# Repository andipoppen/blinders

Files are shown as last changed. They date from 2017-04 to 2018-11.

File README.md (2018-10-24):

# BLE controlled and motorized window blind

This project is a based on a [motorized window blind](https://www.instructables.com/id/Motorized-WiFi-IKEA-Roller-Blind/) that is using the IKEA Tupplur blind. 

The difference from the original is that this project uses BLE to control the window blind and the BLE module is built in the motor holder.

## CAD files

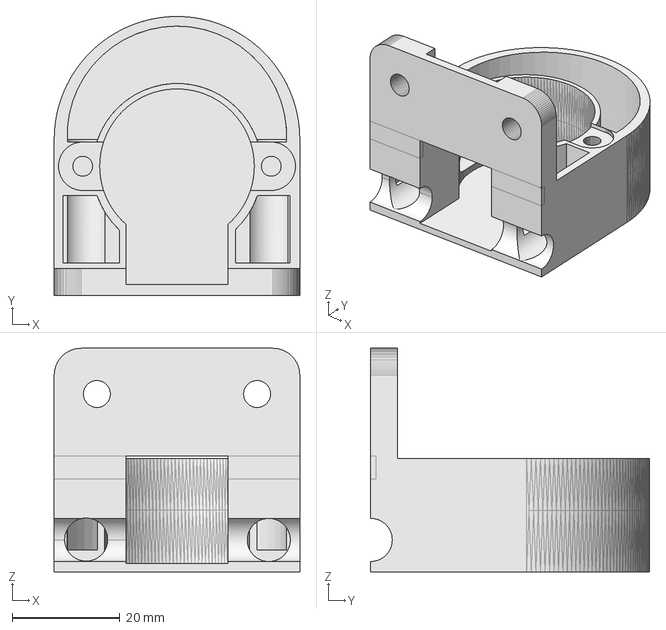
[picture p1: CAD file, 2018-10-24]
3d/mount_base.FCStd
45.6 x 51.8 x 41.5 mm

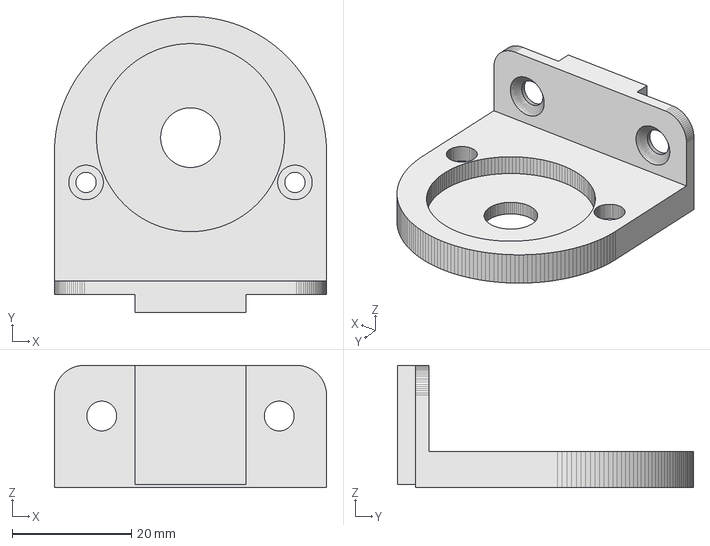
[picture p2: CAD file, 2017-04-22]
3d/mount_cover.FCStd
45.6 x 49.6 x 20.5 mm

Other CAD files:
3d/mount_base.stl
3d/mount_cover.stl

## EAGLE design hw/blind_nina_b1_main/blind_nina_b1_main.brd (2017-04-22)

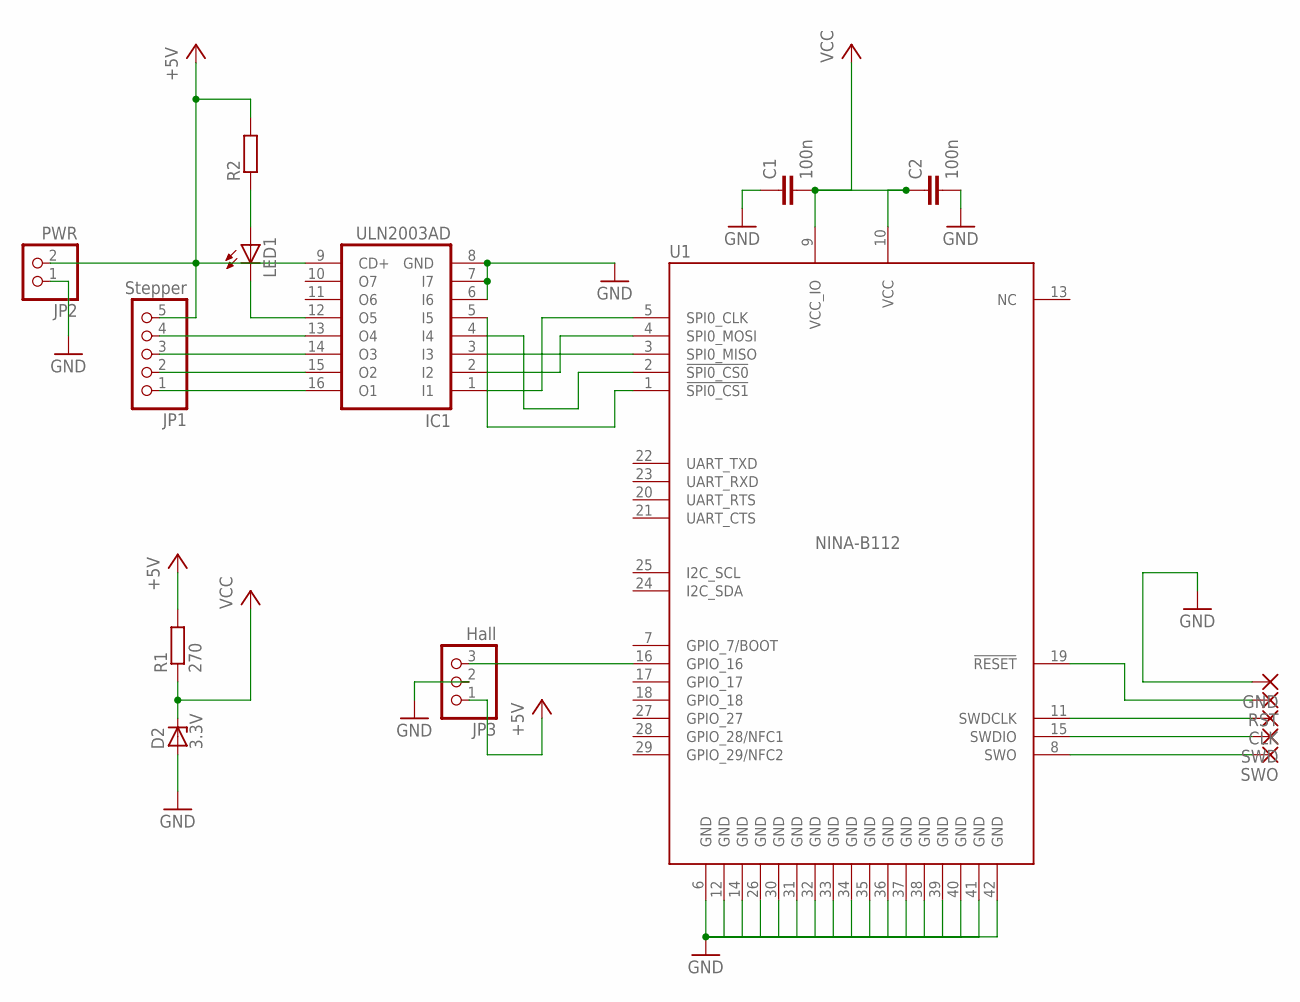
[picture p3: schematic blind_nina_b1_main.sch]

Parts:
C1, C2: 100n; C0603
CLK: SMD2; SMD1,27-2,54
D2: 3.3V; SOD80C
GND: SMD2; SMD1,27-2,54
IC1: ULN2003AD; SO16
JP1: Stepper; 1X05
JP2: PWR; 1X02
JP3: Hall; 1X03
LED1: LED_E; LED_1206
R1: 270; R1210W
R2: R-EU_R0603; R0603
RST: SMD2; SMD1,27-2,54
SWD: SMD2; SMD1,27-2,54
SWO: SMD2; SMD1,27-2,54
U1: NINA-B112; NINA112-42

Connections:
+5V: IC1.9 (CD+), JP1.5, JP2.2, JP3.1, R1.2, R2.2
GND: C1.1, C2.2, D2.A, GND.1, IC1.6 (I6), IC1.7 (I7), IC1.8 (GND), JP2.1, JP3.2, U1.6 (GND), U1.12 (GND), U1.14 (GND), U1.26 (GND), U1.30 (GND), U1.31 (GND), U1.32 (GND), U1.33 (GND), U1.34 (GND), U1.35 (GND), U1.36 (GND), U1.37 (GND), U1.38 (GND), U1.39 (GND), U1.40 (GND), U1.41 (GND), U1.42 (GND)
unnamed: IC1.1 (I1), U1.5 (SPI0_CLK)
unnamed: IC1.2 (I2), U1.4 (SPI0_MOSI)
unnamed: IC1.3 (I3), U1.3 (SPI0_MISO)
unnamed: IC1.4 (I4), U1.2 (!SPI0_CS0)
unnamed: SWO.1, U1.8 (SWO)
unnamed: IC1.16 (O1), JP1.1
unnamed: IC1.15 (O2), JP1.2
unnamed: IC1.14 (O3), JP1.3
unnamed: IC1.13 (O4), JP1.4
unnamed: SWD.1, U1.15 (SWDIO)
unnamed: CLK.1, U1.11 (SWDCLK)
unnamed: RST.1, U1.19 (!RESET)
unnamed: IC1.12 (O5), LED1.C
unnamed: JP3.3, U1.16 (GPIO_16)
unnamed: LED1.A, R2.1
unnamed: IC1.5 (I5), U1.1 (!SPI0_CS1!)
VCC: C1.2, C2.1, D2.C, R1.1, U1.9 (VCC_IO), U1.10 (VCC)

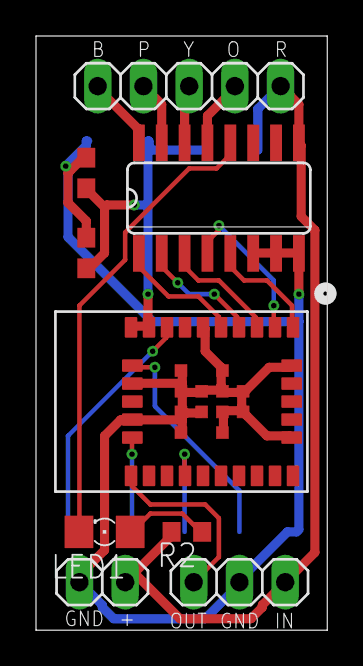
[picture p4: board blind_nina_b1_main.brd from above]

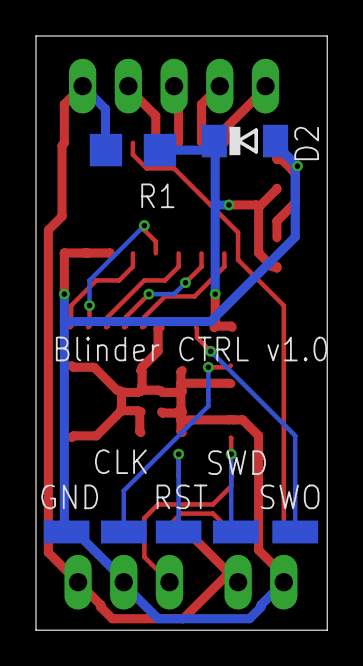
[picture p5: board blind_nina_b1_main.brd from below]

Board: 2 copper layers, 16.2 x 33.0 mm, 16 parts (7 on the bottom side), 19 nets.

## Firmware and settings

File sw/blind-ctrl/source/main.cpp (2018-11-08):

#include "mbed.h"
#include "sMotor.h"
#include "PinDetect.h"
#include <events/mbed_events.h>
#include <mbed.h>
#include "ble/BLE.h"
#include "BlindService.h"
//#include "DataStorage.h"

//DataStorage ds;
DigitalOut ledR(D9);
BLE* myBle = 0;

sMotor motor(D13, D11, D12, D10); // creates new stepper motor: IN1, IN2, IN3, IN4

int step_speed = 1000; // set default motor speed
int numstep = (4076/8)/10; // defines full turn of 360 degree

#define DEFAULT_DOWN_CALIBRATE_POSITION 12000
#define DEFAULT_DOWN_POSITION 8700 // 0x21FC bottom measured
#define DEFAULT_UP_POSITION 100


static int32_t _position = 0; // This is the position where the HALL effekt magnetic sensor is triggered
static int32_t _upPosition = DEFAULT_UP_POSITION; // Slighlty below the HALL effect sensor
static int32_t _bottomPosition = DEFAULT_DOWN_POSITION; // Bottom position of the blind
static int32_t _topPosition = -DEFAULT_DOWN_POSITION*2 - DEFAULT_UP_POSITION; // Top position of the blind. Can actually not go all the way but to make calibration possible from the bottom position

void handleHallSensorFall();

DigitalOut actuatedLED(LED1, 0);

InterruptIn hallSensorIn(A5); // NINA_B1_GPIO_16

const static char     DEVICE_NAME[] = "Blinds";
static const uint16_t uuid16_list[] = { BlindService::BLIND_SERVICE_UUID };

static EventQueue eventQueue(
    /* event count */10 * /* event size */ 32
    );

BlindService *blindServicePtr;


PinDetect pin(SW1);

enum State {
    WaitForTopPos,
    IdleTop,
    IdleBottom,
    Going2Top,
    Going2Bottom,
    Failure
};


static void enterGoing2Top();
static void enterFailure();
static void exitGoing2Top();
static void stepMotorUp();
static void stepMotorDown();


static State _state = IdleBottom;

#define SET_STATE(state) set_state(state,#state)

void set_state(State state, const char *state_str)
{
    _state = state;
    printf("State change to: %s\n", state_str);
}

void stepMotorUp()
{
    motor.step(numstep*100, 1, step_speed); // number of steps, direction, speed
    _position -= numstep;
    motor.disable();
}

void stepMotorDown()
{
    motor.step(numstep*100, 0, step_speed); // number of steps, direction, speed
    _position += numstep;
    motor.disable();
}

static void decrease_position()
{
    _position -= numstep;
    myBle->gattServer().write(blindServicePtr->getValueHandlePos(), (uint8_t*)&_position, 4);
    printf("Pos = %d\n", _position);
}

static void increase_position()
{
    _position += numstep;
    myBle->gattServer().write(blindServicePtr->getValueHandlePos(), (uint8_t*)&_position, 4);
    printf("Pos = %d\n", _position);
}

static void motor_thread() {
    int count = 0;
    ledR = 0;
   
    //pin.mode(PullUp);
    //pin.attach_asserted( &keyPressed );
    //pin.attach_deasserted(&keyReleased);
    //pin.attach_asserted_held( &keyPressedHeld );
    //pin.attach_deasserted_held(&keyReleasedHeld);
    pin.setSampleFrequency();

    // Main motor loop
    while (1)
    {
        count++;
        switch (_state)
        {
        case Going2Top:
            if (_position > _topPosition)
            {
                motor.step(numstep, 1, step_speed); // number of steps, direction, speed
                decrease_position();
            }
            else
            {
                handleHallSensorFall(); // Emulate that we got the sensor indication
                    //SET_STATE(IdleTop);
                //enterFailure();
            }
            break;
        case WaitForTopPos:
            motor.step(numstep, 0, step_speed); // number of steps, direction, speed
            increase_position();
            if(_position > _upPosition)
            {
                SET_STATE(IdleTop);
            }
            break;
        case Going2Bottom:
            if (_position < _bottomPosition)
            {
                motor.step(numstep, 0, step_speed); // number of steps, direction, speed
                increase_position();
            }
            else
            {
                SET_STATE(IdleBottom);
            }
            break;
        default:
            break;
        }
        wait_us(step_speed);    
        motor.disable();
    }
}


void disconnectionCallback(const Gap::DisconnectionCallbackParams_t *params)
{
    (void)params;
    BLE::Instance().gap().startAdvertising();
}

void blinkCallback(void)
{
    ledR = !ledR.read();
    printf("ledR = %d\n",ledR.read());
    
}
/*
void onDataReadCallback(const GattReadCallbackParams *params) {
    if ((params->handle == blindServicePtr->getValueHandlePos())) {
        
    }
}
*/
/**
* This callback allows the LEDService to receive updates to the ledState Characteristic.
*
* @param[in] params
*     Information about the characterisitc being updated.
*/
void onDataWrittenCallback(const GattWriteCallbackParams *params) {
    if ((params->handle == blindServicePtr->getValueHandleCmd()) && (params->len == 1)) {
        switch (*(params->data))
        {
        case BlindService::BLIND_CMD_UP:
            switch (_state)
            {
            case IdleBottom:
            case Going2Bottom:
                enterGoing2Top();
                break;
            default:
                break;
            }
            break;
        case BlindService::BLIND_CMD_DOWN:
            switch (_state)
            {
            case IdleTop:
            case Going2Top:
                exitGoing2Top();
                SET_STATE(Going2Bottom);
                break;
            default:
                break;
            }
            break;
        case BlindService::BLIND_CMD_TOGGLE:
            switch (_state)
            {
            case IdleTop:
                SET_STATE(Going2Bottom);
                break;
            case IdleBottom:
                enterGoing2Top();
                break;
            case Going2Bottom:
                SET_STATE(IdleBottom);
                break;
            case Going2Top:
                exitGoing2Top();
                SET_STATE(IdleTop);
                break;
            }
            break;
        case BlindService::BLIND_CMD_UP_CALIBRATE:
            _upPosition = DEFAULT_UP_POSITION; // Stop at default up position
            enterGoing2Top();
            break;
        case BlindService::BLIND_CMD_DOWN_CALIBRATE:
            _bottomPosition = DEFAULT_DOWN_CALIBRATE_POSITION; // Big enough value to make it go down all the way
            SET_STATE(Going2Bottom);
            break;
        case BlindService::BLIND_CMD_SET_UP_POS:
            _upPosition = _position;
            SET_STATE(IdleTop);
            break;
        case BlindService::BLIND_CMD_SET_BOTTOM_POS:
            _bottomPosition = _position;
            SET_STATE(IdleBottom);
            break;
            
        default:
            // Ignore
            break;
        }
    }
}

/**
* This function is called when the ble initialization process has failled
*/
void onBleInitError(BLE &ble, ble_error_t error)
{
    /* Initialization error handling should go here */
}

/**
* Callback triggered when the ble initialization process has finished
*/
void bleInitComplete(BLE::InitializationCompleteCallbackContext *params)
{
    BLE&        myBle = params->ble;
    ble_error_t error = params->error;

    if (error != BLE_ERROR_NONE) {
        /* In case of error, forward the error handling to onBleInitError */
        onBleInitError(myBle, error);
        return;
    }

    /* Ensure that it is the default instance of BLE */
    if (myBle.getInstanceID() != BLE::DEFAULT_INSTANCE) {
        return;
    }

    myBle.gap().onDisconnection(disconnectionCallback);
    myBle.gattServer().onDataWritten(onDataWrittenCallback);
   // myBle.gattServer().onDataRead(onDataReadCallback);

    bool initialValueForBlindCharacteristic = false;
    uint32_t initialValueForBlindCharacteristicPos = 0;
    blindServicePtr = new BlindService(myBle, initialValueForBlindCharacteristic, initialValueForBlindCharacteristicPos);

    /* setup advertising */
    myBle.gap().accumulateAdvertisingPayload(GapAdvertisingData::BREDR_NOT_SUPPORTED | GapAdvertisingData::LE_GENERAL_DISCOVERABLE);
    myBle.gap().accumulateAdvertisingPayload(GapAdvertisingData::COMPLETE_LIST_16BIT_SERVICE_IDS, (uint8_t *)uuid16_list, sizeof(uuid16_list));
    myBle.gap().accumulateAdvertisingPayload(GapAdvertisingData::COMPLETE_LOCAL_NAME, (uint8_t *)DEVICE_NAME, sizeof(DEVICE_NAME));
    myBle.gap().setAdvertisingType(GapAdvertisingParams::ADV_CONNECTABLE_UNDIRECTED);
    myBle.gap().setAdvertisingInterval(1000); /* 1000ms. */
    myBle.gap().startAdvertising();
    
}

void scheduleBleEventsProcessing(BLE::OnEventsToProcessCallbackContext* context) {
    BLE &myBle = BLE::Instance();
    eventQueue.call(Callback<void()>(&myBle, &BLE::processEvents));
}

void enterGoing2Top()
{
    SET_STATE(Going2Top);
    // TODO start timer
}

void exitGoing2Top()
{
    // TODO stop timer
}

void enterFailure()
{
    eventQueue.call_every(1000, blinkCallback);
}

void handleHallSensorFall()
{
    switch (_state)
    {
    case Going2Top:
        {
        _position = 0; // Calibrate position
        SET_STATE(WaitForTopPos);
        exitGoing2Top();
        }
        break;
    default:
        // Ignore
        break;
    }
}


Thread _motor_thread;


int main()
{
    printf("Start\n");


    myBle = &(BLE::Instance());
    myBle->onEventsToProcess(scheduleBleEventsProcessing);
    myBle->init(bleInitComplete);

    hallSensorIn.mode(PullUp);
    hallSensorIn.fall(&handleHallSensorFall);

    SET_STATE(Going2Top);
    _motor_thread.start(motor_thread);
    //printf(" Motor thread started\n");

    //ds.write_up_position(500);
    eventQueue.dispatch_forever();

    return 0;
}

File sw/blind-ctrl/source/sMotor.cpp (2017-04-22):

/*
############################################
##           sMotor v0.1 Library          ##
##          created by Samuel Matildes    ##
############################################
        ---- sam.naeec@gmail.com -----
This library was made for 4-Phase Stepper Motors
I don't take any resposability for the damage caused to your equipment.

*/

#include "sMotor.h"

#include "mbed.h"

int motorSpeed; // Steper speed

sMotor::sMotor(PinName A0, PinName A1, PinName A2, PinName A3) : _A0(A0), _A1(A1), _A2(A2), _A3(A3) { // Defenition of motor pins
    _A0=0;
    _A1=0;
    _A2=0;
    _A3=0;
}


void sMotor::anticlockwise() { // rotate the motor 1 step anticlockwise 
    for (int i = 0; i < 8; i++) {

        switch (i) { // activate the ports A0, A2, A3, A3 in a binary sequence for steps
            case 0: {
                _A0=0;
                _A1=0;
                _A2=0;
                _A3=1;
            }
            break;
            case 1: {
                _A0=0;
                _A1=0;
                _A2=1;
                _A3=1;
            }
            break;
            case 2: {
                _A0=0;
                _A1=0;
                _A2=1;
                _A3=0;
            }
            break;
            case 3: {
                _A0=0;
                _A1=1;
                _A2=1;
                _A3=0;
            }
            break;
            case 4: {
                _A0=0;
                _A1=1;
                _A2=0;
                _A3=0;
            }
            break;
            case 5: {
                _A0=1;
                _A1=1;
                _A2=0;
                _A3=0;
            }
            break;
            case 6: {
                _A0=1;
                _A1=0;
                _A2=0;
                _A3=0;
            }
            break;
            case 7: {
                _A0=1;
                _A1=0;
                _A2=0;
                _A3=1;
            }
            break;
        }


        wait_us(motorSpeed); // wait time defines the speed 
    }
}

void sMotor::clockwise() { // rotate the motor 1 step clockwise 
    for (int i = 7; i >= 0; i--) {

        switch (i) {
            case 0: {
                _A0=0;
                _A1=0;
                _A2=0;
                _A3=1;
            }
            break;
            case 1: {
                _A0=0;
                _A1=0;
                _A2=1;
                _A3=1;
            }
            break;
            case 2: {
                _A0=0;
                _A1=0;
                _A2=1;
                _A3=0;
            }
            break;
            case 3: {
                _A0=0;
                _A1=1;
                _A2=1;
                _A3=0;
            }
            break;
            case 4: {
                _A0=0;
                _A1=1;
                _A2=0;
                _A3=0;
            }
            break;
            case 5: {
                _A0=1;
                _A1=1;
                _A2=0;
                _A3=0;
            }
            break;
            case 6: {
                _A0=1;
                _A1=0;
                _A2=0;
                _A3=0;
            }
            break;
            case 7: {
                _A0=1;
                _A1=0;
                _A2=0;
                _A3=1;
            }
            break;
        }


        wait_us(motorSpeed); // wait time defines the speed 
    }
}

void sMotor::disable()
{
    _A0=0;
    _A1=0;
    _A2=0;
    _A3=0;
}

void sMotor::step(int num_steps, int direction, int speed) {// steper function: number of steps, direction (0- right, 1- left), speed (default 1200)
    int count=0; // initalize step count
    motorSpeed=speed; //set motor speed
    if (direction==0) // turn clockwise
        do {
            clockwise();
            count++;
        } while (count<num_steps); // turn number of steps applied 
    else if (direction==1)// turn anticlockwise
        do {
            anticlockwise();
            count++;
        } while (count<num_steps);// turn number of steps applied 

}

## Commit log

2017-04-26 Fixed nicer and bigger cutouts. Fixed better naming of cuts
    [mount_base.FCStd, mount_base.stl]
2018-10-19 Added first version of SW
    [mbed.sdf]
2018-10-24 Updated mount_base
    [mount_base.FCStd, mount_base.stl]
2018-10-24 Renamed blinder -> blind
    [blind_nina_b1_main.brd, blind_nina_b1_main.sch]
2018-11-08 Fixed name clash for ble. Uncommented DataStorage.
    [main.cpp]
